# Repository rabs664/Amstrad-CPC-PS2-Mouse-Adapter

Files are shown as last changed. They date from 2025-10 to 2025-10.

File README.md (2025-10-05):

# Amstrad-CPC-PS2-Mouse-Adapter
This is a reproduction of Bryce's PS2 Mouse Adapter, see [CPC Wiki PS2 Mouse](https://www.cpcwiki.eu/index.php?title=PS2Mouse)

>[!NOTE]
>Acknowledgements go to Bryce for posting the origin design to the CPC Wiki. Many Thanks.

Amstrad CPC PS2 Mouse Adapter

>[!CAUTION]
>USE AT YOUR OWN RISK.
>There is always the risk that the PS2 Mouse Adapter could cause harm to your CPC. Although I have tested the PS2 Mouse Adapter, there is no guarantee that it will work properly under all circumstances.

This repository contains my reproduction of the Bryce's PS2 Mouse Adapter and includes the KiCad 7.0 project files, gerber files and a 3D printable case. For all other information see [CPC Wiki PS2 Mouse](https://www.cpcwiki.eu/index.php?title=PS2Mouse)

Amstrad CPC PS2 Mouse Adapter 2

>[!NOTE]
>I used a straight through DB9 Male to Female cable similar to the one below to connect the PS2 Mouse Adapter.
>
>DB9 Male to Female
>
>Power was provided using a 5.5mmx2.1mm DC Power Splitter Cable similar to the one below.
>Power Splitter cable

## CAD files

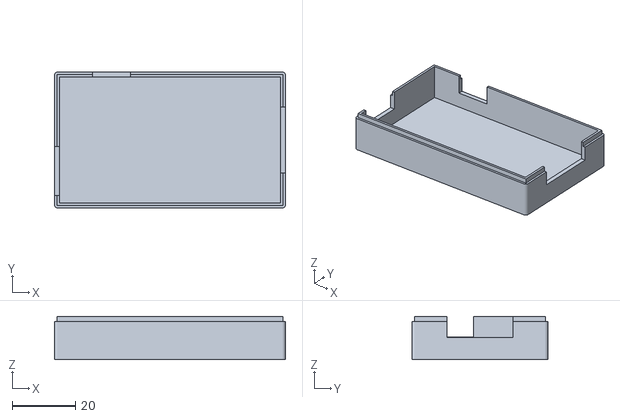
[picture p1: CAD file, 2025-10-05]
Bottom Case.stl
73.0 x 43.0 x 13.6

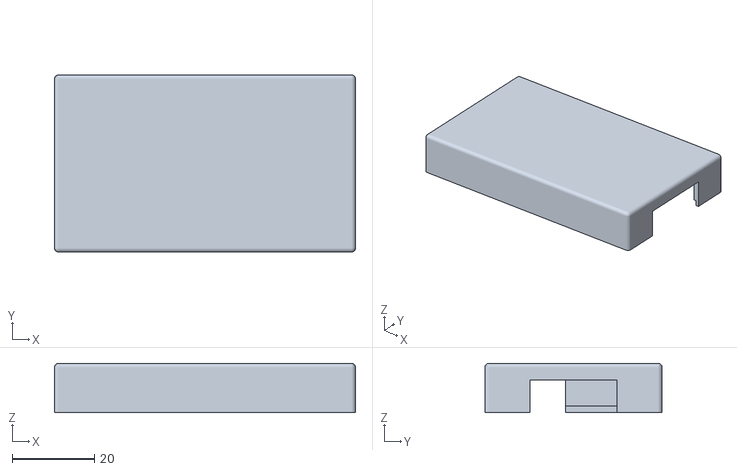
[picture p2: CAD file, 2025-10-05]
Top Case.stl
73.0 x 43.0 x 12.0

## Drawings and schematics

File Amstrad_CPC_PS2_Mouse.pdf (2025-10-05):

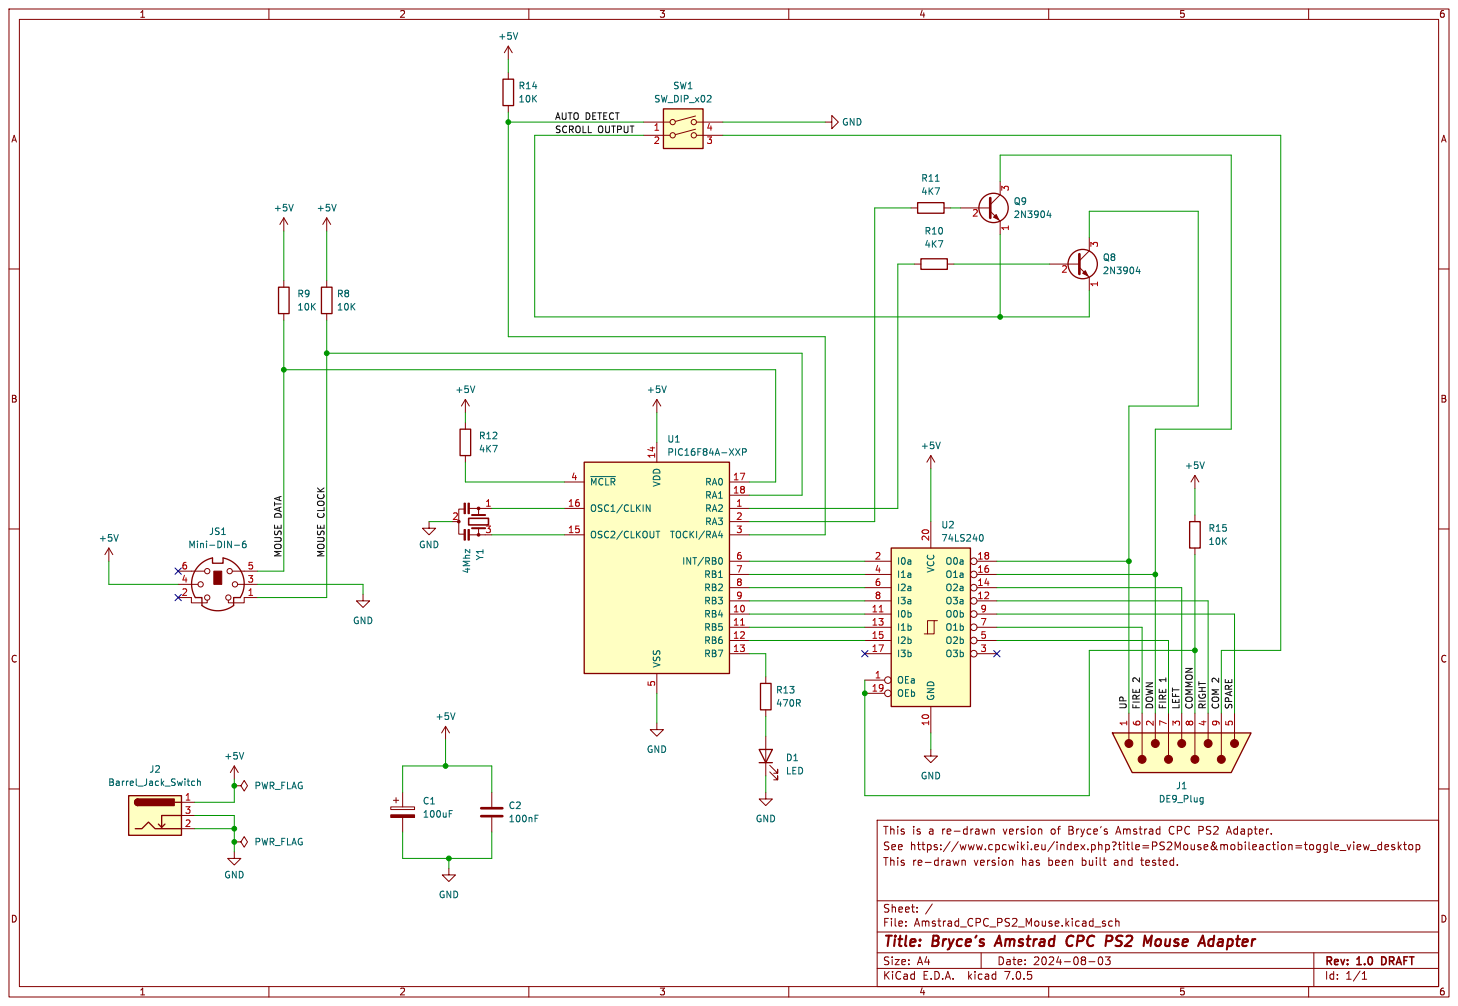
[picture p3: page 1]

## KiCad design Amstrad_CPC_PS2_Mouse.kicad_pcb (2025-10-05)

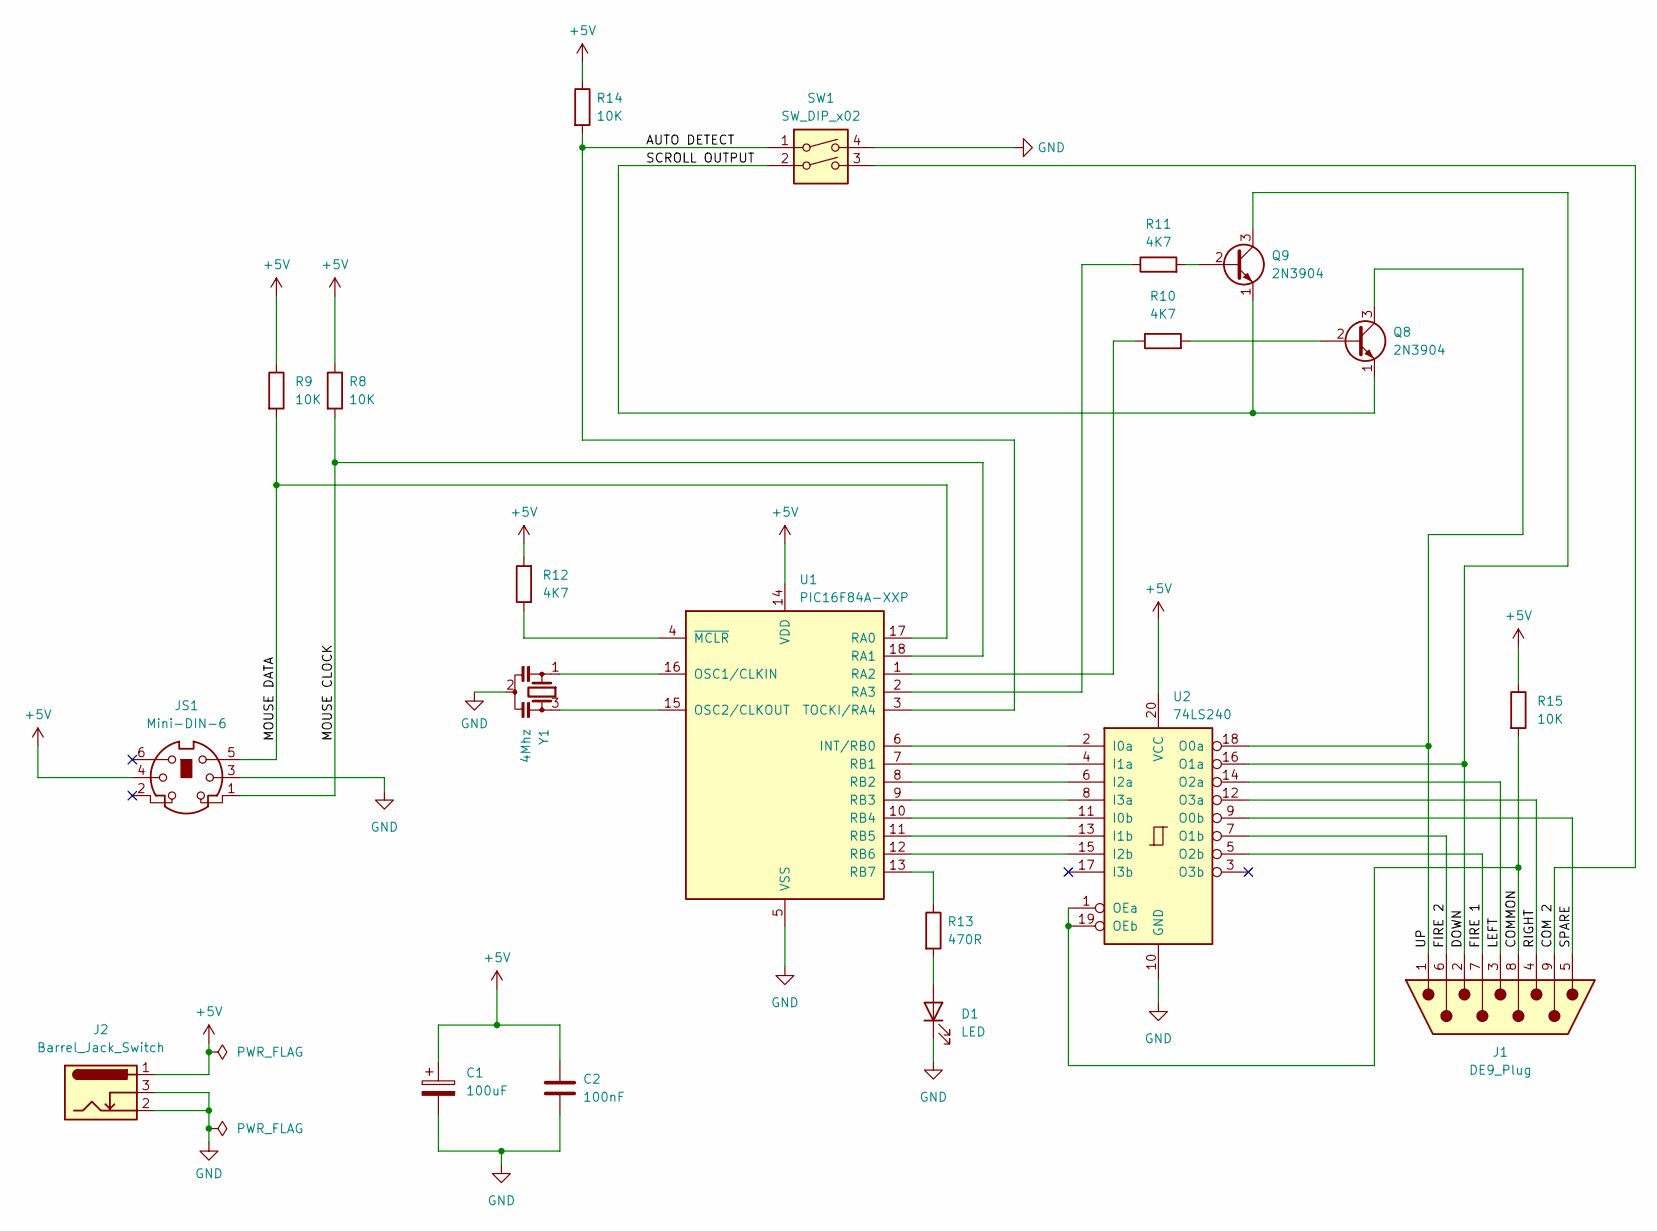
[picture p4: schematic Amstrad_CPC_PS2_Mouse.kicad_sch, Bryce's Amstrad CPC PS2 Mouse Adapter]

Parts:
C1: 100uF; CP_Radial_D6.3mm_P2.50mm
C2: 100nF; C_Disc_D5.0mm_W2.5mm_P5.00mm
D1: LED; LED_D1.8mm_W3.3mm_H2.4mm
J1: DE9_Plug; DSUB-9_Female_Horizontal_P2.77x2.84mm_EdgePinOffset7.70mm_H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
J2: Barrel_Jack_Switch; BarrelJack_Horizontal
JS1: Mini-DIN-6; Connector_Mini-DIN_Female_6Pin_2rows
Q8, Q9: 2N3904; TO-92_Inline
R8, R9, R14, R15: 10K; R_Axial_DIN0207_L6.3mm_D2.5mm_P10.16mm_Horizontal
R10, R11, R12: 4K7; R_Axial_DIN0207_L6.3mm_D2.5mm_P10.16mm_Horizontal
R13: 470R; R_Axial_DIN0207_L6.3mm_D2.5mm_P10.16mm_Horizontal
SW1: SW_DIP_x02; SW_DIP_SPSTx02_Slide_9.78x7.26mm_W7.62mm_P2.54mm
U1: PIC16F84A-XXP; DIP-18_W7.62mm_Socket_LongPads
U2: 74LS240; DIP-20_W7.62mm_Socket_LongPads
Y1: 4Mhz; Resonator-3Pin_W10.0mm_H5.0mm

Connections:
+5V: C1.1, C2.1, J2.1, JS1.4, R8.1, R9.1, R12.2, R14.1, R15.1, U1.14 (VDD), U2.20 (VCC)
/AUTO DETECT: R14.2, SW1.1, U1.3 (TOCKI/RA4)
/COM 2: J1.9, SW1.3
/COMMON: J1.8, R15.2, U2.1 (OEa), U2.19 (OEb)
/DOWN: J1.2, Q9.3 (C), U2.16 (O1a)
/FIRE 1: J1.7, U2.5 (O2b)
/FIRE 2: J1.6, U2.7 (O1b)
/LEFT: J1.3, U2.14 (O2a)
/MOUSE CLOCK: JS1.1, R8.2, U1.18 (RA1)
/MOUSE DATA: JS1.5, R9.2, U1.17 (RA0)
/RIGHT: J1.4, U2.12 (O3a)
/SCROLL OUTPUT: Q8.1 (E), Q9.1 (E), SW1.2
/SPARE: J1.5, U2.9 (O0b)
/UP: J1.1, Q8.3 (C), U2.18 (O0a)
GND: C1.2, C2.2, D1.1 (K), J2.2, J2.3, JS1.3, SW1.4, U1.5 (VSS), U2.10 (GND), Y1.2
unnamed: D1.2 (A), R13.2
unnamed: Q8.2 (B), R10.2
unnamed: Q9.2 (B), R11.2
unnamed: U1.6 (INT/RB0), U2.2 (I0a)
unnamed: U1.16 (OSC1/CLKIN), Y1.1
unnamed: U1.15 (OSC2/CLKOUT), Y1.3
unnamed: R10.1, U1.1 (RA2)
unnamed: R11.1, U1.2 (RA3)
unnamed: U1.7 (RB1), U2.4 (I1a)
unnamed: U1.8 (RB2), U2.6 (I2a)
unnamed: U1.9 (RB3), U2.8 (I3a)
unnamed: U1.10 (RB4), U2.11 (I0b)
unnamed: U1.11 (RB5), U2.13 (I1b)
unnamed: U1.12 (RB6), U2.15 (I2b)
unnamed: R13.1, U1.13 (RB7)
unnamed: R12.1, U1.4 (~MCLR)

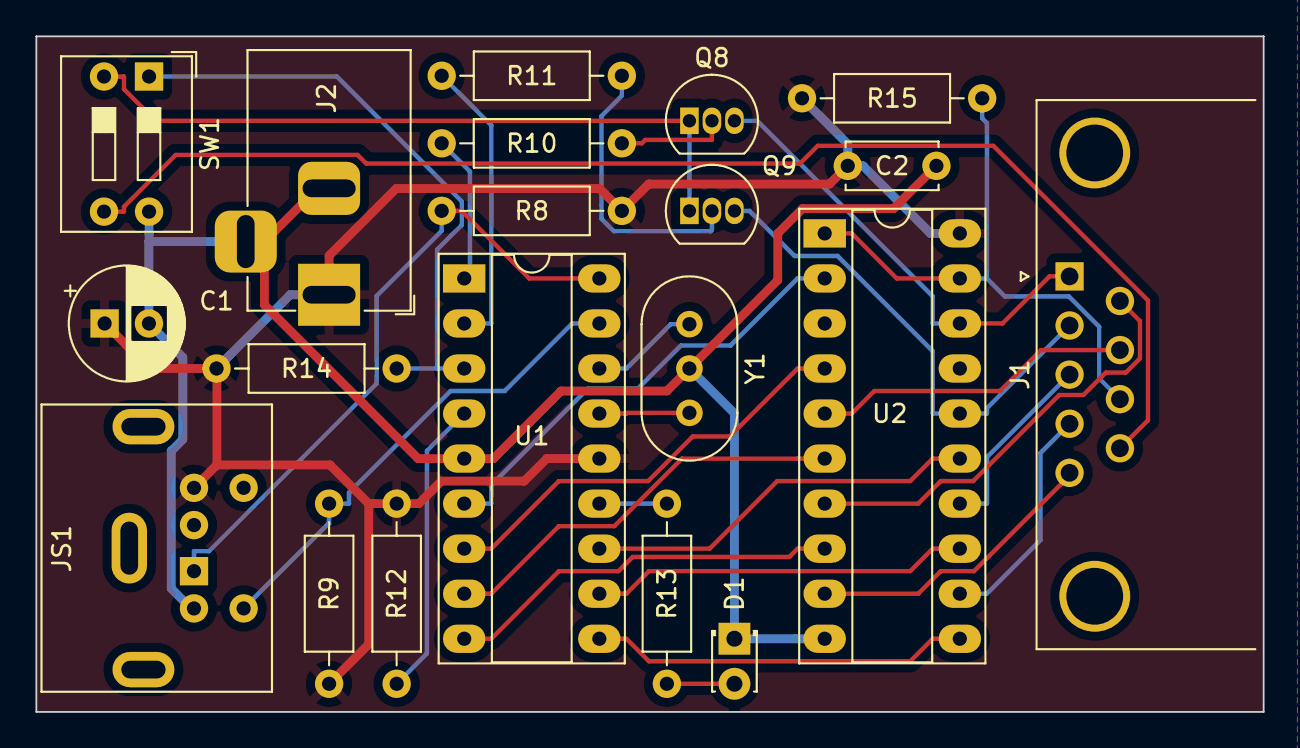
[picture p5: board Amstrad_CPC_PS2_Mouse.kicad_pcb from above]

Board: 2 copper layers, 69.2 x 38.1 mm, 20 parts (0 on the bottom side), 31 nets.
